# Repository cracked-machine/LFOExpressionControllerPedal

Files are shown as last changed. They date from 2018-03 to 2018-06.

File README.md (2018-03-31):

# LFOExpressionControllerPedal
This pedal replaces the traditional treadle/rocker expression pedal as an input into other guitar effects pedals.
Traditional expression pedals allow the player to control a variable resistance via an analog potentiometer in the expression pedal. This pedal creates an LFO signal that sweeps a digital potentiometer. 

The DSP is provided by an ATMEGA328P MCU, which transmits the binary encoded waveform data to a MCP41050 digital potentiometer via SPI. Eight waveforms are available: Sine, Square, RampUp, RampDown, Triangle, 8Step, 4Step and Pulse.
These waveforms can be selected via a single SPDT switch. LEDs indicate the selected waveform. A separate analog pot adjusts the frequency speed.

Documentation:

<ul>
  <li><a href="Hardware/SMT/documentation/LFOControllerPedal_SMT.xml">BOM</a></li>
  <li><a href="Hardware/SMT/documentation/LFOExpController_SMT.pdf">Schematic</a></li>
  <li><a href="Hardware/SMT/documentation/LFOExpController_SMT-TOPbrd.svg">Board Layout (TOP)</a></li>
  <li><a href="Hardware/SMT/documentation/LFOExpController_SMT-BOTTOMbrd.svg">Board Layout (BOTTOM)</a></li>
</ul>

<a href="https://github.com/cracked-machine/LFOExpressionControllerPedal">Github</a>|
<a href="https://cracked-machine.github.io/LFOExpressionControllerPedal/">Pages</a>

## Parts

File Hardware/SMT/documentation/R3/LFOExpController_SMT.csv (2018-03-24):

Reference | Value | Footprint | Datasheet
Y_AVRCLK1 | 16MHz | Crystals:Crystal_HC49-4H_Vertical
C_AVRCLK1 | 22pF | Capacitors_SMD:C_0805_HandSoldering
C_AVRCLK2 | 22pF | Capacitors_SMD:C_0805_HandSoldering
C2 | 100nF | Capacitors_SMD:C_0805_HandSoldering
SW_FUNC1 | SW_Push | Buttons_Switches_THT:SW_PUSH_6mm_h5mm
R_FUNC1 | 1K | Resistors_SMD:R_0805_HandSoldering
R_FREQ1 | B1K | Potentiometers:Potentiometer_Bourns_PTV09A-1_Horizontal
R1 | 330R | Resistors_SMD:R_0805_HandSoldering
R3 | 1K | Resistors_SMD:R_0805_HandSoldering
C1 | 100nF | Capacitors_SMD:C_0805_HandSoldering
D_WLED1 | LED | LEDs:LED_0805_HandSoldering
J_ISP1 | Conn_01x04 | Pin_Headers:Pin_Header_Straight_1x04_Pitch2.54mm
SW_EN1 | SW_DPDT_x2 | DPDT_FOOT_ONON_ALPHA_W13MM_D12MM_P5:DPDT_FOOT_ONON_ALPHA_W13MM_D12MM_P5.08MM
R_EN1 | 1K | Resistors_SMD:R_0805_HandSoldering
D_EN1 | LED | LEDs:LED_0805_HandSoldering
R_WLEDA1 | 1K | Resistors_SMD:R_0805_HandSoldering
D_WLED2 | LED | LEDs:LED_0805_HandSoldering
R_WLEDA2 | 1K | Resistors_SMD:R_0805_HandSoldering
D_WLED3 | LED | LEDs:LED_0805_HandSoldering
R_WLEDA3 | 1K | Resistors_SMD:R_0805_HandSoldering
D_WLED4 | LED | LEDs:LED_0805_HandSoldering
R_WLEDA4 | 1K | Resistors_SMD:R_0805_HandSoldering
D_WLED5 | LED | LEDs:LED_0805_HandSoldering
R_WLEDA5 | 1K | Resistors_SMD:R_0805_HandSoldering
D_WLED6 | LED | LEDs:LED_0805_HandSoldering
R_WLEDA6 | 1K | Resistors_SMD:R_0805_HandSoldering
U_9REG5 | LM317_3PinPackage | TO_SOT_Packages_SMD:SOT-223-3_TabPin2
U_WLEDMUX1 | _4051 | Housings_SOIC:SOIC-16_3.9x9.9mm_Pitch1.27mm
J_DC1 | _Barrel_Jack | Connectors:BARREL_JACK
U_AVR1 | _ATMEGA168A-AU | Housings_QFP:TQFP-32_7x7mm_Pitch0.8mm
D_InProtect1 | _D_Schottky | Diodes_SMD:D_SOD-123
J_OUT1 | Audio-Jack-3_3Switches | TRS635mmJack:TRS635mmJack
R_DB1 | 1K | Resistors_SMD:R_0805_HandSoldering
C_DB1 | 1uF | Capacitors_SMD:C_0805_HandSoldering
R_MUXIN1 | 470R | Resistors_SMD:R_0805_HandSoldering
C_BP1 | 100nF | Capacitors_SMD:C_0805_HandSoldering
C_BP5 | 100nF | Capacitors_SMD:C_0805_HandSoldering
J_MAIN2AUX1 | Conn_01x08 | Pin_Headers:Pin_Header_Straight_1x08_Pitch2.54mm
JP_GND1 | Jumper_NC_Dual | NetTie-II_SMD_FakeConnected:NetTie-II_SMD_GraphicallyConnected
U_DIGPOT1 | _MCP41050 | Housings_SOIC:SOIC-8_3.9x4.9mm_Pitch1.27mm
J_AUX2MAIN1 | _Conn_01x08 | Pin_Headers:Pin_Header_Straight_1x08_Pitch2.54mm

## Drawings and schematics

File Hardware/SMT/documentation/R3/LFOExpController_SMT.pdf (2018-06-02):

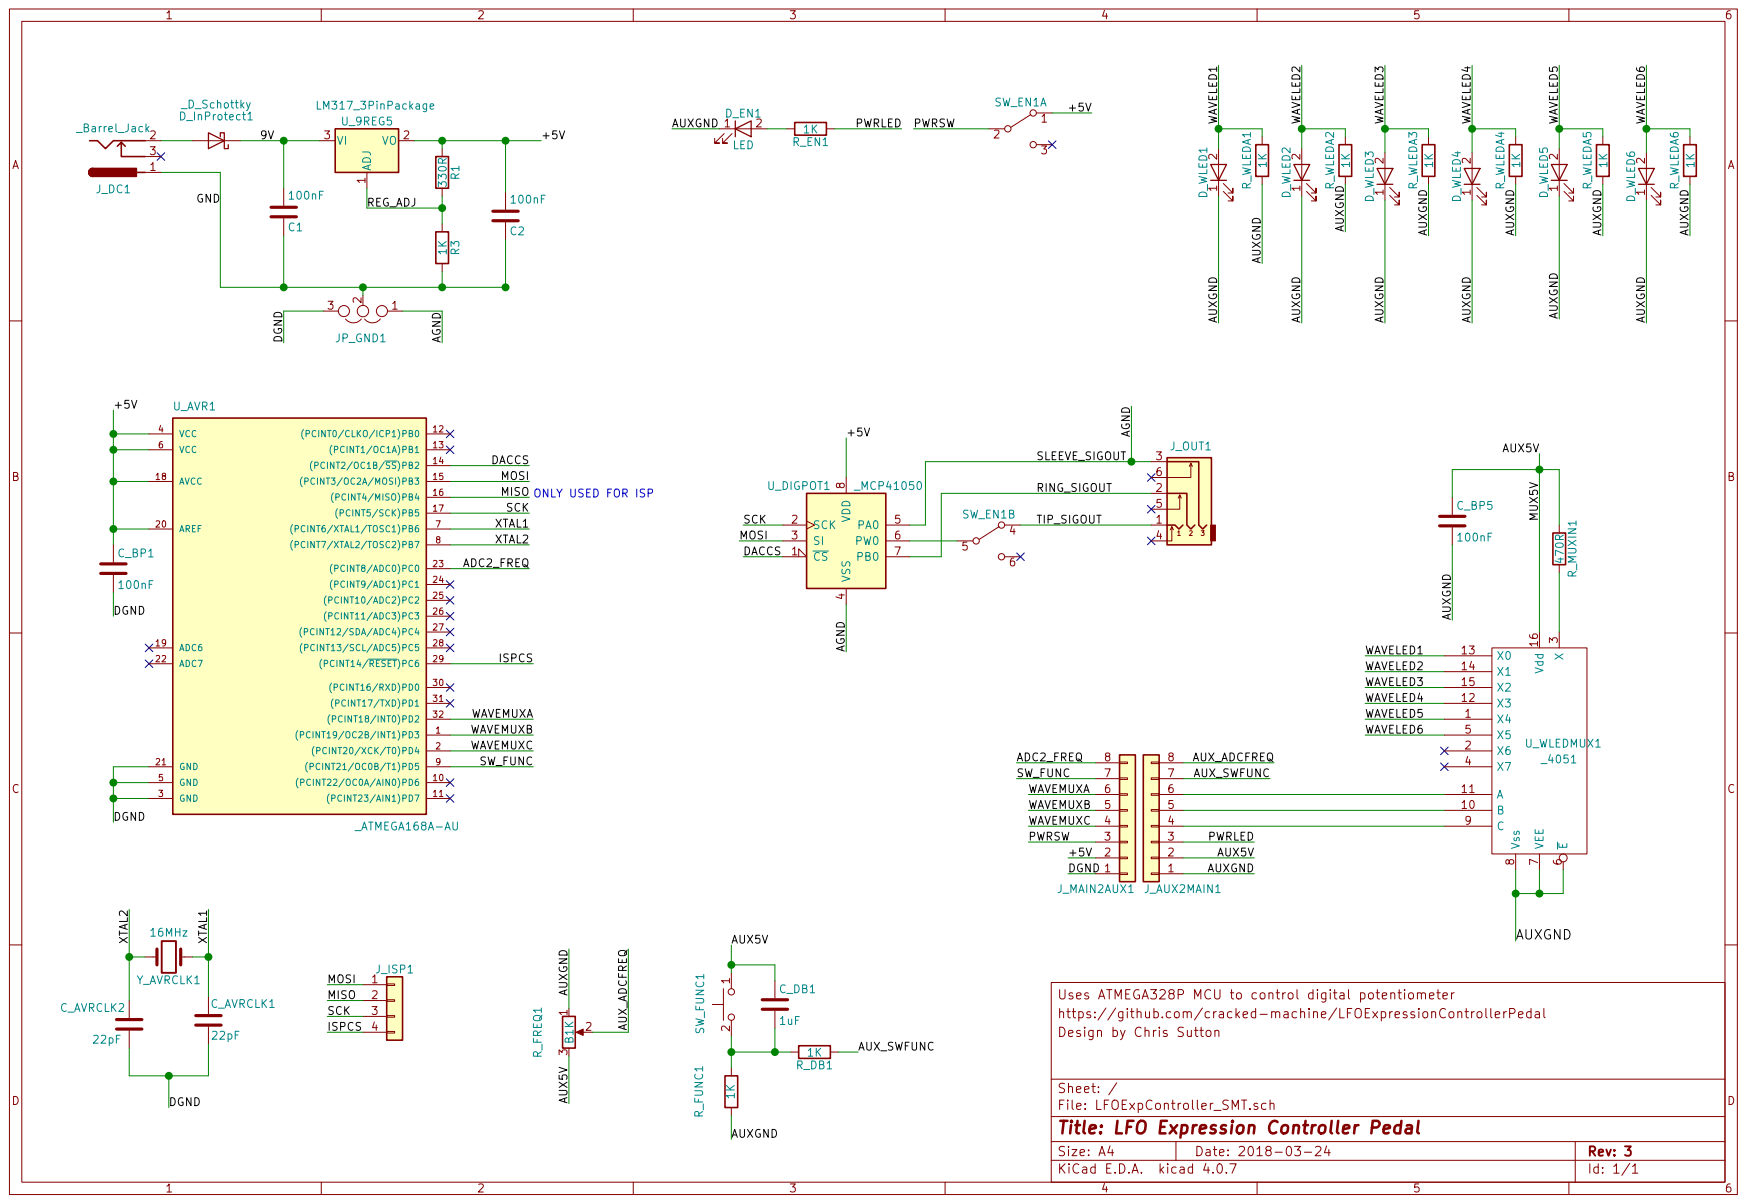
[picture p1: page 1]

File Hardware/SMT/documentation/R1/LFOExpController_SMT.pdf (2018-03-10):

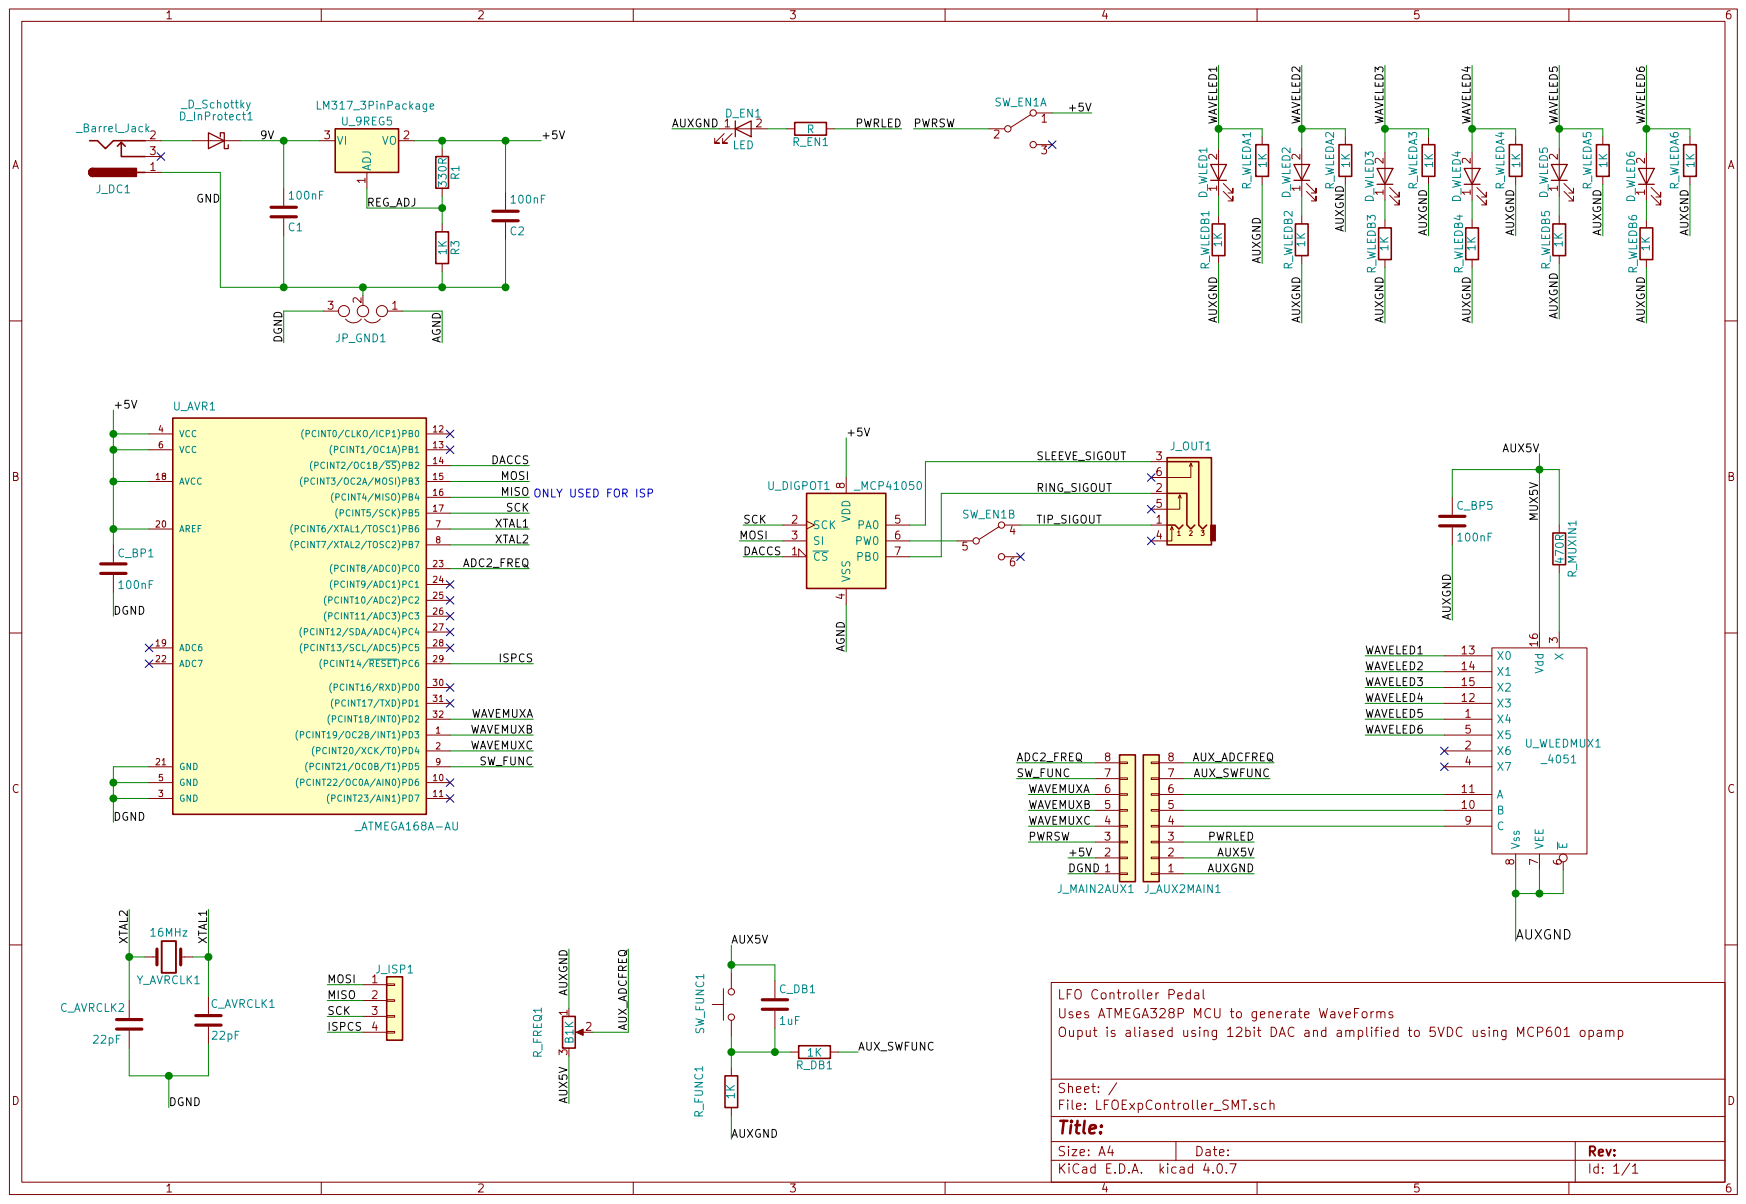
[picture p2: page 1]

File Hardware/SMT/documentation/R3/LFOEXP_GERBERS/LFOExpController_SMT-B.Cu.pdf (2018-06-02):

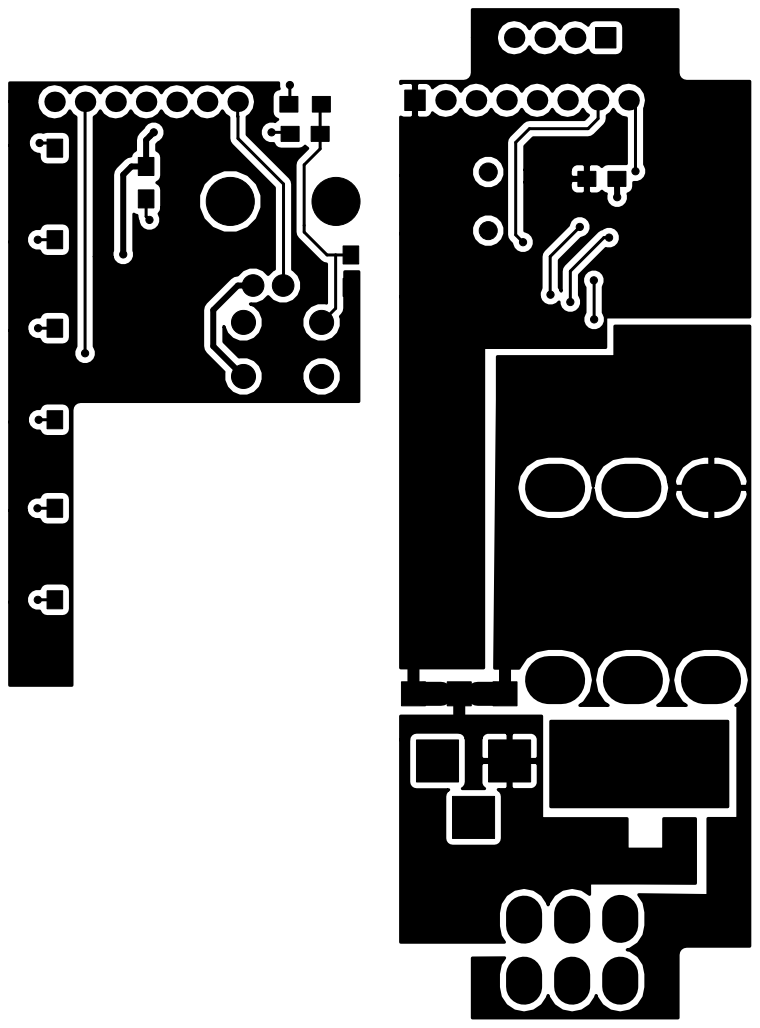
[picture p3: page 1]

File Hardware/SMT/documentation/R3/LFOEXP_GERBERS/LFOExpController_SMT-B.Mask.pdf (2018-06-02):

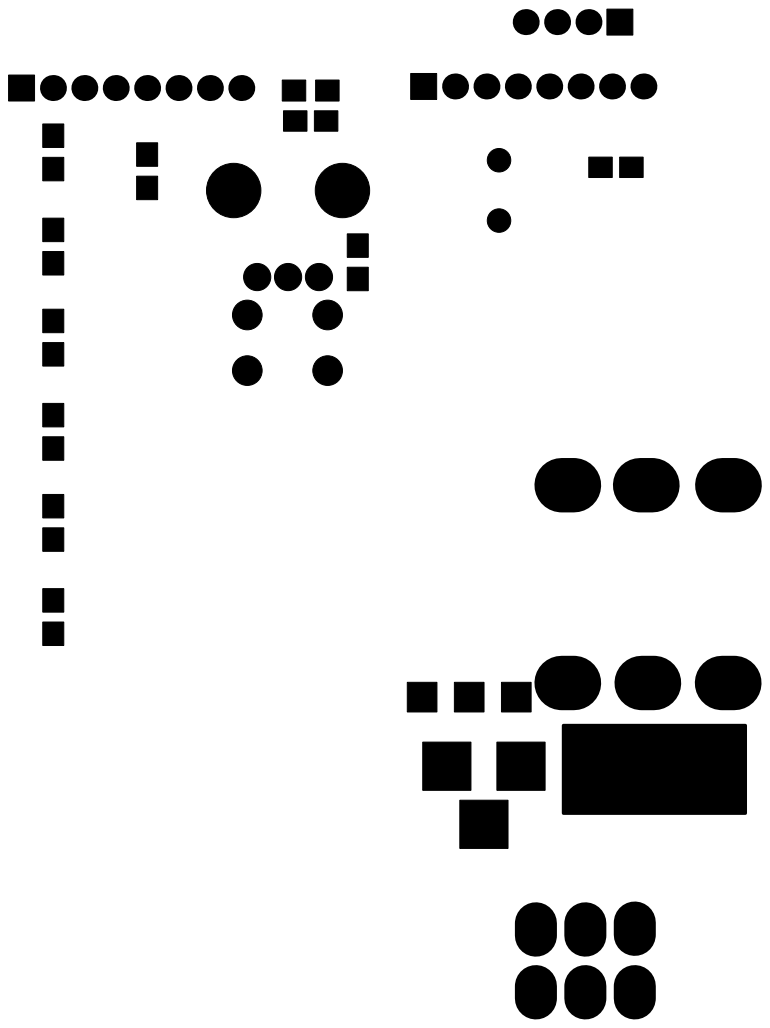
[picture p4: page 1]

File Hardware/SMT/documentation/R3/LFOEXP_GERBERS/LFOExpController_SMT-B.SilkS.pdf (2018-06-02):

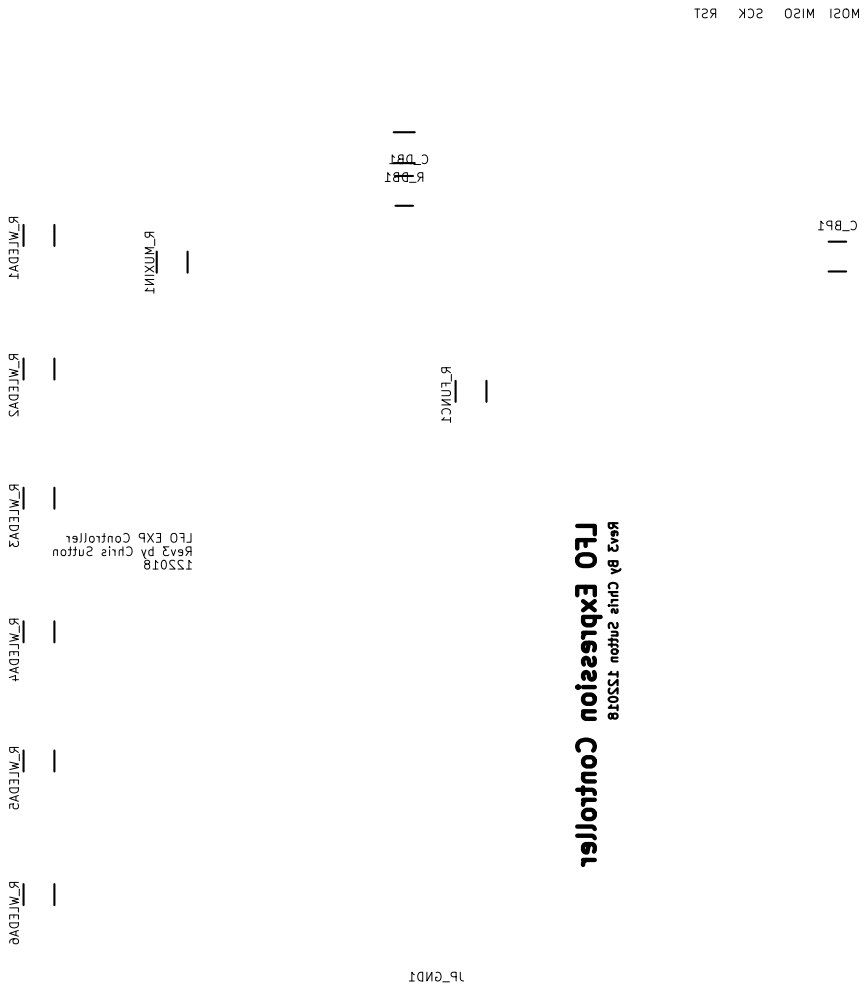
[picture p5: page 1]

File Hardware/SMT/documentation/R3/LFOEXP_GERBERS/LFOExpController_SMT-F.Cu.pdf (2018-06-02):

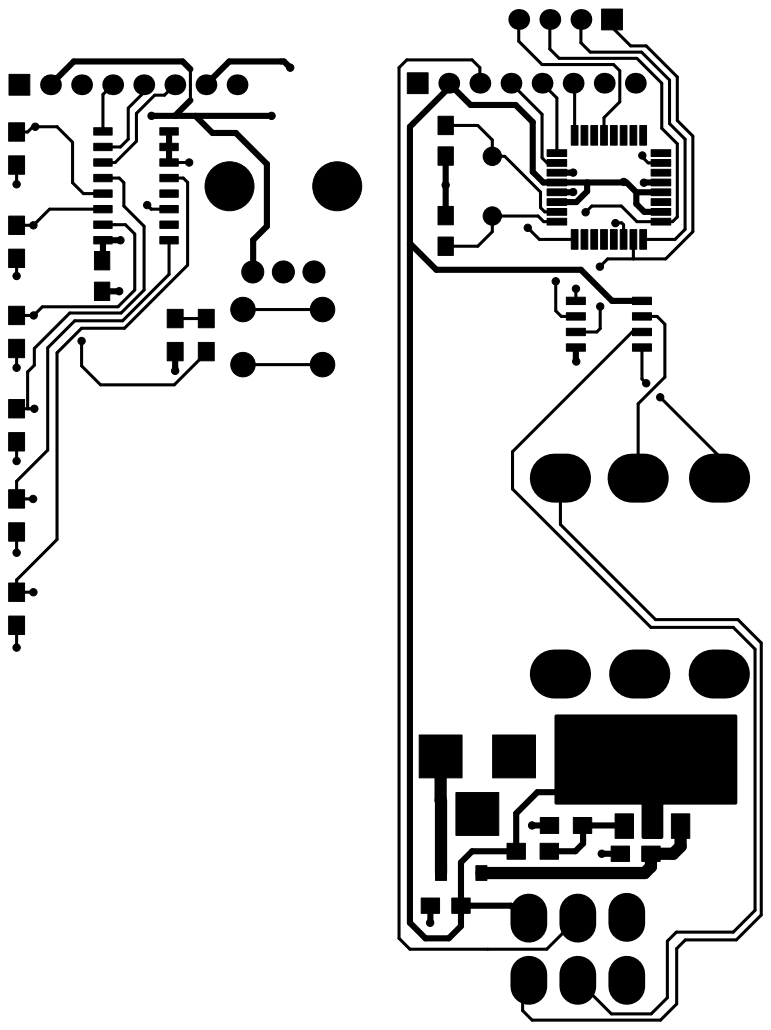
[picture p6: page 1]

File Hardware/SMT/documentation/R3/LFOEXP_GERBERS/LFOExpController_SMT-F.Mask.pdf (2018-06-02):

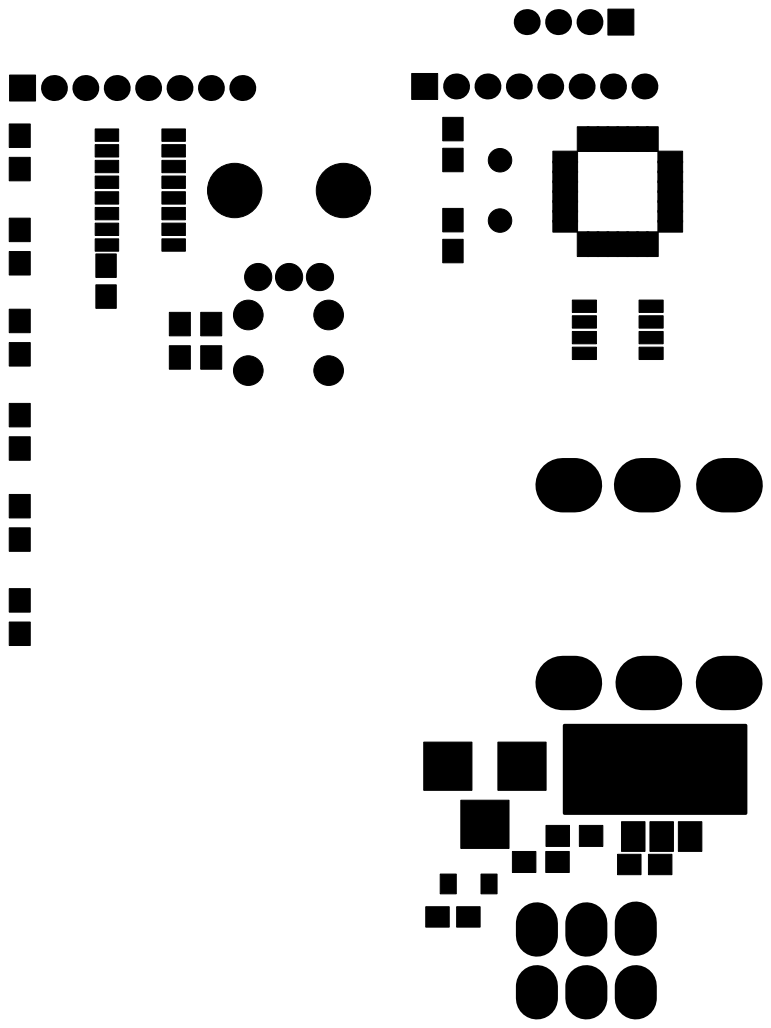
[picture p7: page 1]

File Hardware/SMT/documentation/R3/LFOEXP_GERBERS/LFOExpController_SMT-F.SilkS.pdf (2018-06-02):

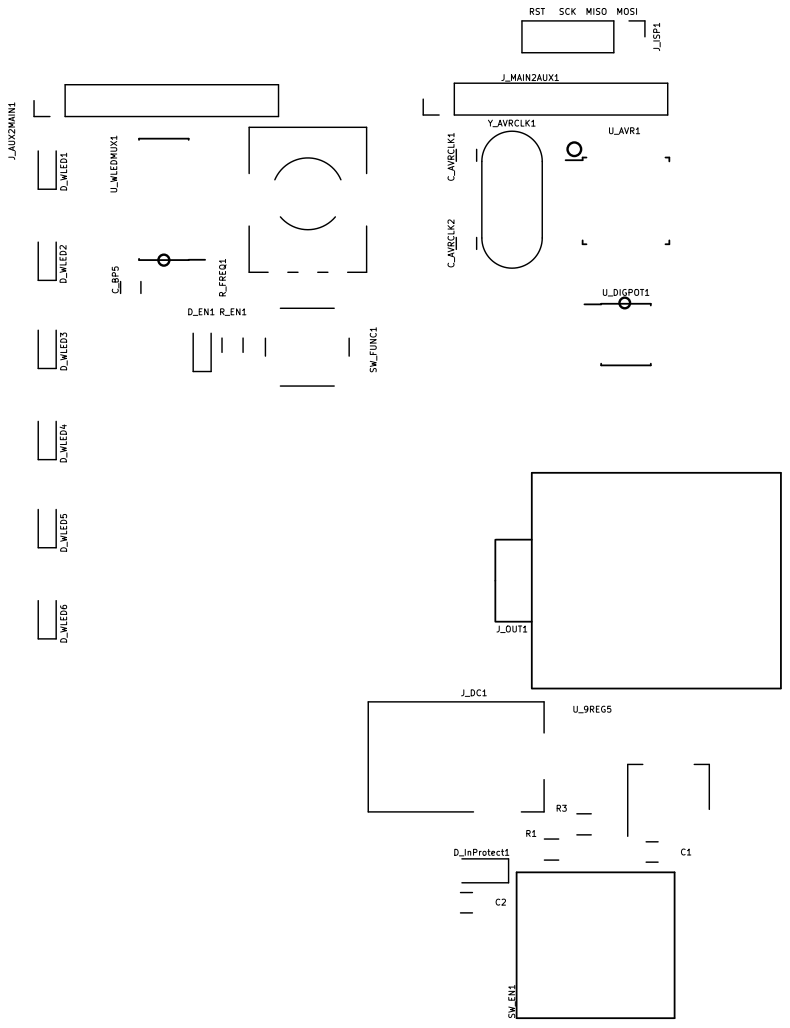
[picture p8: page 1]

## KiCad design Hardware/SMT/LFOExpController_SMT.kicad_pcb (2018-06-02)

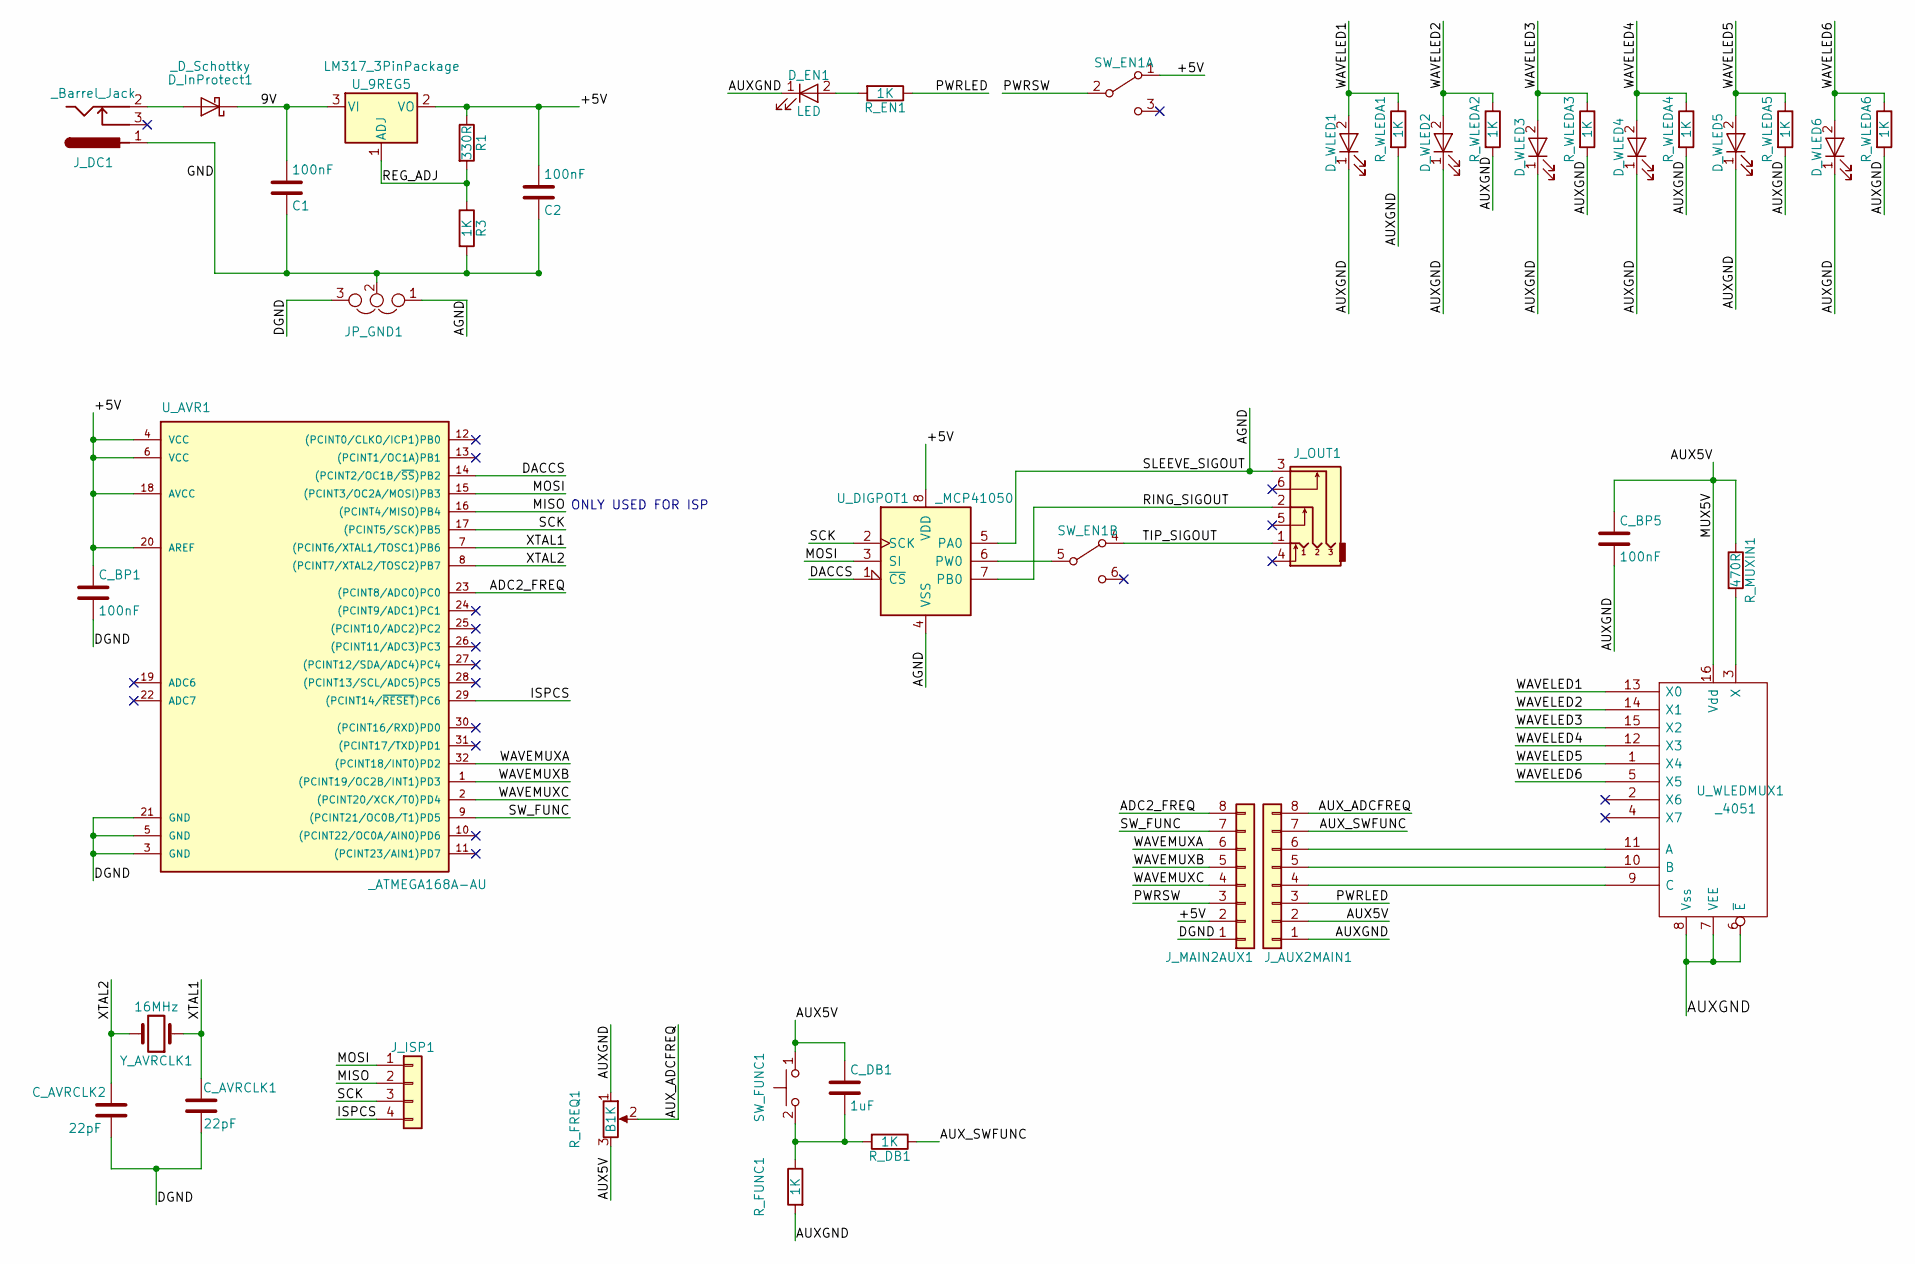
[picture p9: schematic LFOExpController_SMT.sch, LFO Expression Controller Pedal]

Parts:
C1, C2: 100nF; C_0805_HandSoldering
C_AVRCLK1, C_AVRCLK2: 22pF; C_0805_HandSoldering
C_BP1, C_BP5: 100nF; C_0805_HandSoldering
C_DB1: 1uF; C_0805_HandSoldering
D_EN1: LED; LED_0805_HandSoldering
D_InProtect1: _D_Schottky; D_SOD-123
D_WLED1, D_WLED2, D_WLED3, D_WLED4, D_WLED5, D_WLED6: LED; LED_0805_HandSoldering
JP_GND1: Jumper_NC_Dual; NetTie-II_SMD_GraphicallyConnected
J_AUX2MAIN1: _Conn_01x08; Pin_Header_Straight_1x08_Pitch2.54mm
J_DC1: _Barrel_Jack; BARREL_JACK
J_ISP1: Conn_01x04; Pin_Header_Straight_1x04_Pitch2.54mm
J_MAIN2AUX1: Conn_01x08; Pin_Header_Straight_1x08_Pitch2.54mm
J_OUT1: Audio-Jack-3_3Switches; TRS635mmJack
R1: 330R; R_0805_HandSoldering
R3: 1K; R_0805_HandSoldering
R_DB1: 1K; R_0805_HandSoldering
R_EN1: 1K; R_0805_HandSoldering
R_FREQ1: B1K; Potentiometer_Bourns_PTV09A-1_Horizontal
R_FUNC1: 1K; R_0805_HandSoldering
R_MUXIN1: 470R; R_0805_HandSoldering
R_WLEDA1, R_WLEDA2, R_WLEDA3, R_WLEDA4, R_WLEDA5, R_WLEDA6: 1K; R_0805_HandSoldering
SW_EN1: SW_DPDT_x2; DPDT_FOOT_ONON_ALPHA_W13MM_D12MM_P5.08MM
SW_FUNC1: SW_Push; SW_PUSH_6mm_h5mm
U_9REG5: LM317_3PinPackage; SOT-223-3_TabPin2
U_AVR1: _ATMEGA168A-AU; TQFP-32_7x7mm_Pitch0.8mm
U_DIGPOT1: _MCP41050; SOIC-8_3.9x4.9mm_Pitch1.27mm
U_WLEDMUX1: _4051; SOIC-16_3.9x9.9mm_Pitch1.27mm
Y_AVRCLK1: 16MHz; Crystal_HC49-4H_Vertical

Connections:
/9V: C1.2, D_InProtect1.1 (K), U_9REG5.3 (VI)
/+5V: C2.2, C_BP1.1, J_MAIN2AUX1.2, R1.1, SW_EN1.1 (A), U_9REG5.2 (VO), U_AVR1.4 (VCC), U_AVR1.6 (VCC), U_AVR1.18 (AVCC), U_AVR1.20 (AREF), U_DIGPOT1.8 (VDD)
/ADC2_FREQ: J_MAIN2AUX1.8, U_AVR1.23 ((PCINT8/ADC0)PC0)
/AGND: JP_GND1.1, J_OUT1.3, U_DIGPOT1.4 (VSS), U_DIGPOT1.5 (PA0)
/AUX5V: C_BP5.1, C_DB1.1, J_AUX2MAIN1.2, R_FREQ1.3, R_MUXIN1.1, SW_FUNC1.1, U_WLEDMUX1.16 (Vdd)
/AUXGND: C_BP5.2, D_EN1.1 (K), D_WLED1.1 (K), D_WLED2.1 (K), D_WLED3.1 (K), D_WLED4.1 (K), D_WLED5.1 (K), D_WLED6.1 (K), J_AUX2MAIN1.1, R_FREQ1.1, R_FUNC1.2, R_WLEDA1.2, R_WLEDA2.2, R_WLEDA3.2, R_WLEDA4.2, R_WLEDA5.2, R_WLEDA6.2, U_WLEDMUX1.6 (~E), U_WLEDMUX1.7 (VEE), U_WLEDMUX1.8 (Vss)
/AUX_ADCFREQ: J_AUX2MAIN1.8, R_FREQ1.2
/AUX_SWFUNC: J_AUX2MAIN1.7, R_DB1.1
/DACCS: U_AVR1.14 ((PCINT2/OC1B/~SS~)PB2), U_DIGPOT1.1 (~CS)
/DGND: C_AVRCLK1.1, C_AVRCLK2.1, C_BP1.2, JP_GND1.3, J_MAIN2AUX1.1, U_AVR1.3 (GND), U_AVR1.5 (GND), U_AVR1.21 (GND)
/GND: C1.1, C2.1, JP_GND1.2, J_DC1.1, R3.2
/ISPCS: J_ISP1.4, U_AVR1.29 ((PCINT14/~RESET~)PC6)
/MISO: J_ISP1.2, U_AVR1.16 ((PCINT4/MISO)PB4)
/MOSI: J_ISP1.1, U_AVR1.15 ((PCINT3/OC2A/MOSI)PB3), U_DIGPOT1.3 (SI)
/PWRLED: J_AUX2MAIN1.3, R_EN1.1
/PWRSW: J_MAIN2AUX1.3, SW_EN1.2 (B)
/REG_ADJ: R1.2, R3.1, U_9REG5.1 (ADJ)
/RING_SIGOUT: J_OUT1.2, U_DIGPOT1.7 (PB0)
/SCK: J_ISP1.3, U_AVR1.17 ((PCINT5/SCK)PB5), U_DIGPOT1.2 (SCK)
/SW_FUNC: J_MAIN2AUX1.7, U_AVR1.9 ((PCINT21/OC0B/T1)PD5)
/TIP_SIGOUT: J_OUT1.1, SW_EN1.4 (A)
/WAVELED1: D_WLED1.2 (A), R_WLEDA1.1, U_WLEDMUX1.13 (X0)
/WAVELED2: D_WLED2.2 (A), R_WLEDA2.1, U_WLEDMUX1.14 (X1)
/WAVELED3: D_WLED3.2 (A), R_WLEDA3.1, U_WLEDMUX1.15 (X2)
/WAVELED4: D_WLED4.2 (A), R_WLEDA4.1, U_WLEDMUX1.12 (X3)
/WAVELED5: D_WLED5.2 (A), R_WLEDA5.1, U_WLEDMUX1.1 (X4)
/WAVELED6: D_WLED6.2 (A), R_WLEDA6.1, U_WLEDMUX1.5 (X5)
/WAVEMUXA: J_MAIN2AUX1.6, U_AVR1.32 ((PCINT18/INT0)PD2)
/WAVEMUXB: J_MAIN2AUX1.5, U_AVR1.1 ((PCINT19/OC2B/INT1)PD3)
/WAVEMUXC: J_MAIN2AUX1.4, U_AVR1.2 ((PCINT20/XCK/T0)PD4)
/XTAL1: C_AVRCLK1.2, U_AVR1.7 ((PCINT6/XTAL1/TOSC1)PB6), Y_AVRCLK1.1
/XTAL2: C_AVRCLK2.2, U_AVR1.8 ((PCINT7/XTAL2/TOSC2)PB7), Y_AVRCLK1.2
unnamed: C_DB1.2, R_DB1.2, R_FUNC1.1, SW_FUNC1.2
unnamed: D_EN1.2 (A), R_EN1.2
unnamed: D_InProtect1.2 (A), J_DC1.2
unnamed: J_AUX2MAIN1.4, U_WLEDMUX1.9 (C)
unnamed: J_AUX2MAIN1.5, U_WLEDMUX1.10 (B)
unnamed: J_AUX2MAIN1.6, U_WLEDMUX1.11 (A)
unnamed: R_MUXIN1.2, U_WLEDMUX1.3 (X)
unnamed: SW_EN1.5 (B), U_DIGPOT1.6 (PW0)

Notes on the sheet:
ONLY USED FOR ISP

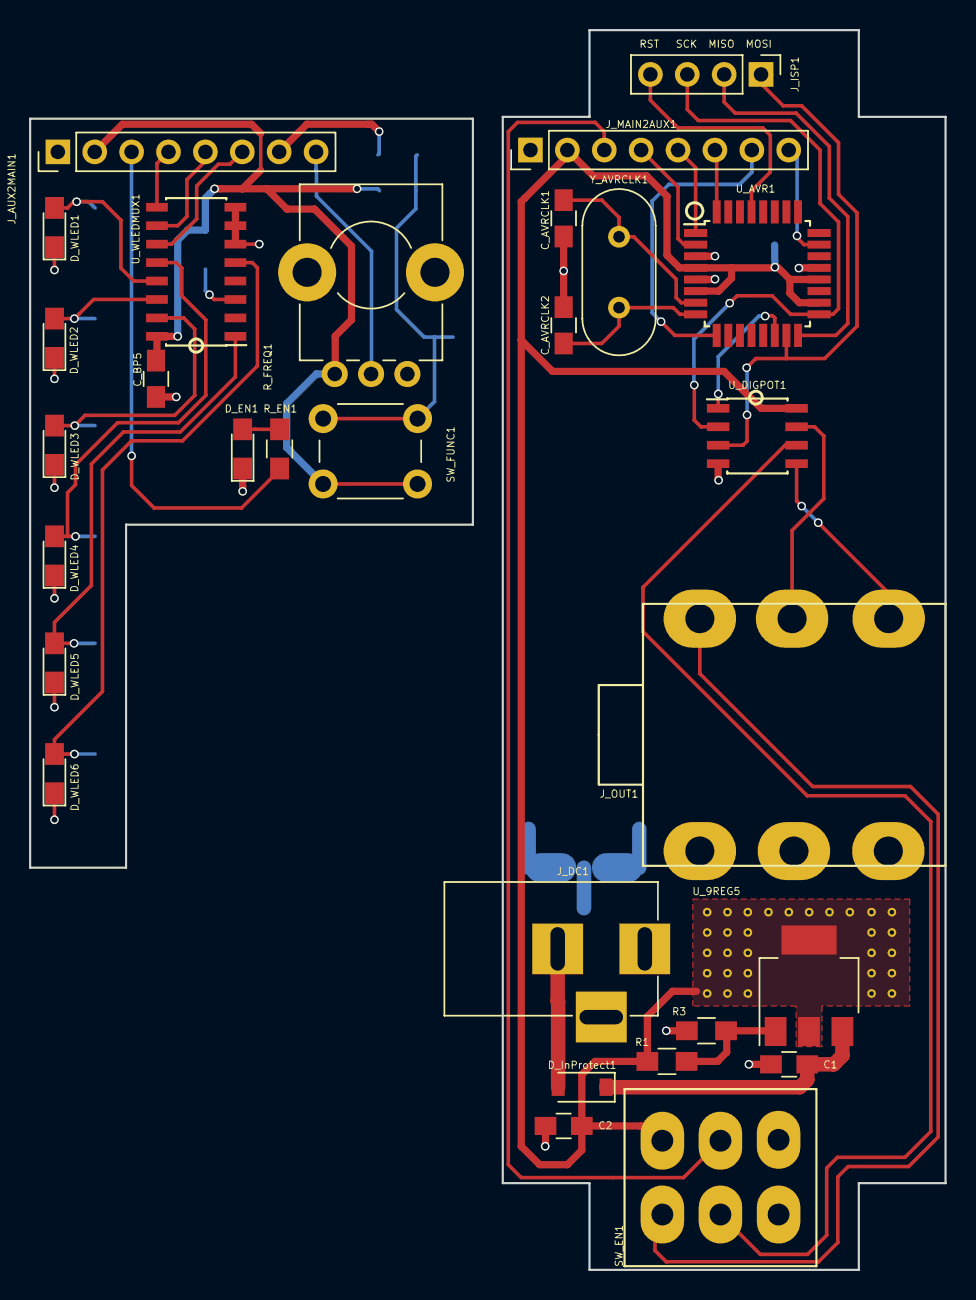
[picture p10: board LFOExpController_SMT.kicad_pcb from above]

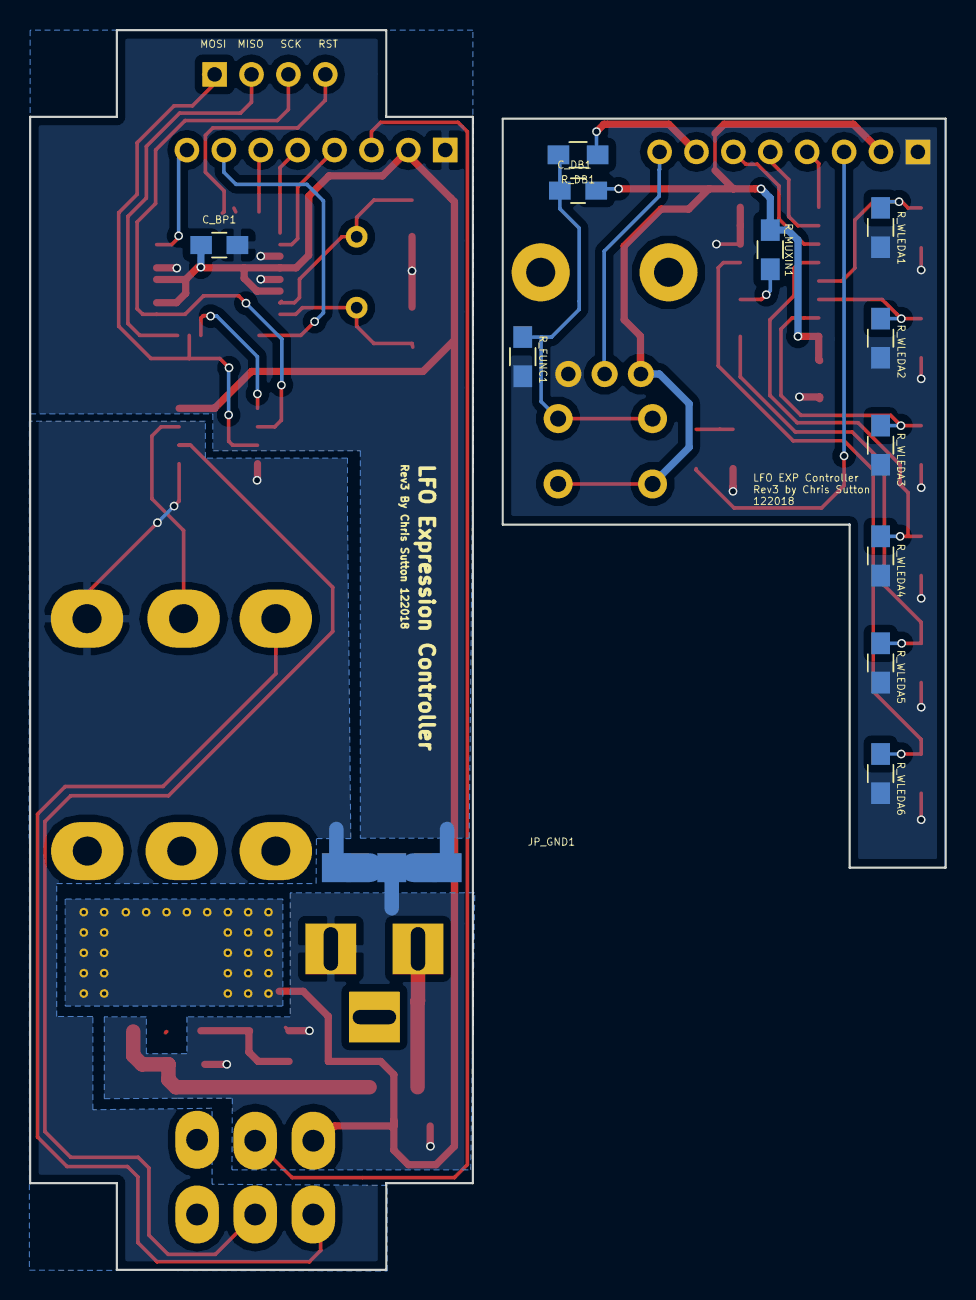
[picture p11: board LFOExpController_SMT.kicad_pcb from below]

Board: 2 copper layers, 63.0 x 85.3 mm, 41 parts (12 on the bottom side), 40 nets.

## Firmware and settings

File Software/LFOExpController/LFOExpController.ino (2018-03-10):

// DWG auxiliary source
#include "LFOExpController_CLK.h"
#include "LFOExpController_SPI.h"



unsigned long DWG_LastDebounceTime = 0;  // the last time the output pin was toggled
unsigned long DWG_DebounceDelay = 400;    // the debounce time; increase if the output flickers
volatile uint8_t DWG_Portdhistory = 0xFF; 

void setup() {
  Serial.begin(9600);
 
  
  PCI_Setup();
  CLK_Setup();
  DSP_Setup();
  SPI_Setup();
  ADC_Setup();
  
}

void loop() {
  int _freqLow = 2;         // increases lower limit of frequency range
  int _logTaper = 384;      // audio/log taper 
  
  if (ADC_FreqInput > 10) {
    // add log taper so that linear potentiometer can be used.
    OCR1A = map(ADC_FreqInput * _freqLow, 0, 1023, 0, _logTaper);
    
  }
  // set LED based on value of DSP_Waveform
  PCI_SetMUX();

}

/////////////////////////////////////////////
/////////////////////////////////////////////
/////  ITERRUPT SERVICE ROUTINES
/////////////////////////////////////////////
/////////////////////////////////////////////



ISR(TIMER1_OVF_vect) {
   // reset SPI pins...?
    DDRB |= _BV(_SS);               // set SS pin to output before enabling SPI (req. for master)
    SPCR |=  _BV(SPE) | _BV(MSTR);  // enable spi as master
    //DDRB |= _BV(_SCK) | _BV(_MOSI); // set pins to output
 
   SPI_SendData();
}

// Interrupt service routine for the ADC completion
ISR(ADC_vect){
  
  
  ADCInput = ADCL;
  ADCInput += ADCH << 8;

  
   switch(ADMUX) {
    case 0x00:
      ADC_FreqInput = ADCInput;
      
     // ADMUX = 0x01;
    break;
    
    /*case 0x01:
      ADC_FreqInput = ADCInput;
      ADMUX = 0x00;
    break;
    */
    
    
  }
  ADCSRA |= _BV(ADSC);
 
}

ISR(PCINT2_vect) {  
   //Serial.println("Test");
    if(PIND & _BV(PCI_WaveIncrPin)) {
      
      (DSP_Waveform == PULSE) ? DSP_Waveform = SINE : DSP_Waveform++;      
      PCI_SetMUX();
      
     
    }
  
}

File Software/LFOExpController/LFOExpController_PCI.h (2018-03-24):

#ifndef DWG_PCI_H_
#define DWG_PCI_H_

// see CD74HCT4051 MUX datasheet function table
// we are using PIND2, PIND3 and PIND4 on the ATMEGA328P to send addresses to MUX
#define MUXCLEAR 0x00    // 000 // 
#define MUXS0 0x02    // 001
#define MUXS1 0x03    // 010  
#define MUXS2 0x04    // 100



// 0x02 2+3
// 0x03 1+3
// 0x04 1+2
// 0x0

/////  ATMEGA328P reference PORTD pin-2-interrupt
// PIND0 = PCINT16
// PIND1 = PCINT17
// PIND2 = PCINT18
// PIND3 = PCINT19
// PIND4 = PCINT20
// PIND5 = PCINT21
// PIND6 = PCINT22
// PIND7 = PCINT23

// PCI_WaveIncrPin. must change BOTH. See above for reference.
int PCI_WaveIncrPin = PIND5; 
int PCI_WaveIncInt = PCINT21;

int PCI_MUXPIN0 = PIND2;
int PCI_MUXPIN1 = PIND3;
int PCI_MUXPIN2 = PIND4;

void PCI_Setup() {
  
  //set PCI_WaveIncrPin = INPUT (0), PCI_MUXS0 = OUTPUT (1)
  DDRD |= ~_BV(PCI_WaveIncrPin) | _BV(PCI_MUXPIN0) | _BV(PCI_MUXPIN1) | _BV(PCI_MUXPIN2);
  
  
  //set PCI_WaveIncrPin = Hi-Z (1)
  PORTD |= _BV(PCI_WaveIncrPin) | _BV(PCI_MUXPIN0) | _BV(PCI_MUXPIN1) | _BV(PCI_MUXPIN2) ;

  //pinMode(PCI_WaveIncrPin, INPUT);
  //pinMode(PCI_MUXPIN0, OUTPUT);
  //pinMode(PCI_MUXPIN1, OUTPUT);
  //pinMode(PCI_MUXPIN2, OUTPUT);
  
  
  PCICR |= _BV(PCIE2);      // enable interrupts for PD 0-7 ports (PCINT16-23)
  PCMSK2 |= _BV(PCI_WaveIncInt) ;   // enable interrupts for PCI_WaveIncrPin
   
}

void PCI_SetMUX() {
  switch(DSP_Waveform) {
        
        case SINE:
            // A0 = LLL
            digitalWrite(PCI_MUXPIN2, LOW);
            digitalWrite(PCI_MUXPIN1, LOW);
            digitalWrite(PCI_MUXPIN0, LOW);
          
          break;
        case TRIANGLE:
            // A1 = LLH
            digitalWrite(PCI_MUXPIN2, LOW);
            digitalWrite(PCI_MUXPIN1, LOW);
            digitalWrite(PCI_MUXPIN0, HIGH);
          break;
        case RAMPUP:
            // A2 = LHL
            digitalWrite(PCI_MUXPIN2, LOW);
            digitalWrite(PCI_MUXPIN1, HIGH);
            digitalWrite(PCI_MUXPIN0, LOW);
          break;
        case STEP4:
            //A3 = LHH
            digitalWrite(PCI_MUXPIN2, LOW);
            digitalWrite(PCI_MUXPIN1, HIGH);
            digitalWrite(PCI_MUXPIN0, HIGH);
          break;
          
        case SQUARE:
            //A4 = HLL
            digitalWrite(PCI_MUXPIN2, HIGH);
            digitalWrite(PCI_MUXPIN1, LOW);
            digitalWrite(PCI_MUXPIN0, LOW);
          break;
         
        case PULSE:
            //A5 = HLH
            digitalWrite(PCI_MUXPIN2, HIGH);
            digitalWrite(PCI_MUXPIN1, LOW);
            digitalWrite(PCI_MUXPIN0, HIGH);
          break;
         
        /*case STEP4:
            //A6 = HHL
            digitalWrite(PCI_MUXPIN2, HIGH);
            digitalWrite(PCI_MUXPIN1, HIGH);
            digitalWrite(PCI_MUXPIN0, LOW);
          break;
        case PULSE:
            //A7 = HHH
            digitalWrite(PCI_MUXPIN2, HIGH);
            digitalWrite(PCI_MUXPIN1, HIGH);
            digitalWrite(PCI_MUXPIN0, HIGH);
          break;
          */
      }

  
}

#endif

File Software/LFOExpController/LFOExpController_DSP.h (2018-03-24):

#ifndef DWG_DSP_H_
#define DWG_DSP_H_

//#define LOOKUP_TABLE_ENABLED

// all possible waveforms
enum DSP_EWAVEFORMS { SINE, TRIANGLE, RAMPUP, STEP4, SQUARE, PULSE } ;

// available waveforms. if you change this order make sure the last item matches one used  in PCINT2_vect condition!
DSP_EWAVEFORMS const DSP_Waveforms[] = { SINE, TRIANGLE, RAMPUP, STEP4, SQUARE, PULSE };

// current selected waveform
int DSP_Waveform;

// sine wave lookup table and sample rate. limit dictated by MCP41050
const int DSP_SampleResolution = 256;  

// counter variable used by all waveforms
int DSP_WaveIndex;

void DSP_Setup() {

  DSP_Waveform = SINE;
}

int DSP_GetAlgorithmicWaveData(DSP_EWAVEFORMS _Waveform) {
      int _multiplier;
      int _halfPeriod=DSP_SampleResolution/2;   // half period
      int _temp;                                 // temp allows serial print debug
      float _tri_temp=0;                        // triangle needs a float
   
      switch(_Waveform) {
          // cases must exist in DSP_EWAVEFORMS and DSP_Waveforms[] OR they MUST be commented out to build successfully!
          case SINE:     
              _temp = (cos(((2.0*PI)/DSP_SampleResolution)*DSP_WaveIndex))*(_halfPeriod-1);
              return _temp += (_halfPeriod-1);
            break;
          
          case SQUARE:
            return (DSP_WaveIndex++ % 256) < 128 ? (0xFF) : 0x00;
            break;

          case RAMPUP:
            _multiplier = 4;
            _temp = DSP_SampleResolution - (_multiplier * (DSP_WaveIndex/4));
            return _temp;
            break;
          
          /*case RAMPDOWN:
            _multiplier = 4;
            _temp = _multiplier * (DSP_WaveIndex/4);
            return _temp;
            break;
          */
          case TRIANGLE:  
            _multiplier = 2;
            _tri_temp = (_halfPeriod - abs(DSP_WaveIndex % (2 * _halfPeriod) - _halfPeriod) );
            _tri_temp = (DSP_SampleResolution-1) - ((_multiplier) * _tri_temp);
            return _tri_temp;
            break;
          /*
          case STEP8:
            _multiplier = 32;
            _temp = DSP_SampleResolution - (_multiplier * (DSP_WaveIndex/_multiplier));
            return _temp;
            break;
          */
          case STEP4:
            _multiplier = 64;
            _temp = DSP_SampleResolution - (_multiplier * (DSP_WaveIndex/_multiplier));
            return _temp;
            break;
            
          case PULSE:
            return (DSP_WaveIndex++ % 256) > 224 ? (0xFF) : 0x00;
            break;
      }
      
 
}





#endif 

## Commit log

2018-03-10 Completed Board Layout
    [LFOExpController_SMT.kicad_pcb, LFOExpController_SMT.sch]
2018-03-11 Generated GERBERS
    [LFOExpController_SMT-B.Cu.gbr, LFOExpController_SMT-B.Mask.gbr, LFOExpController_SMT-B.SilkS.gbr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]
2018-03-24 Revision3 update
    - Added ground to Jack sleeve pin
    - Corrected SW_FUNC circuit
    - Removed R_WLEDB LEDS
    - Modified firmware from eight wavepatterns to six, to allign with Hardware (Sine, Triangle, RampUp, Step4, Square, Pulse)
    - Created R3 documentation
    - Created new GERBERS
    [LFOExpController_SMT.csv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]
2018-03-24 save update
    [LFOExpController_SMT.kicad_pcb]
2018-06-02 board layout update
    - rotated freq pot 180 and moved up 5mm
    - narrowed led strip on daughter board
    [LFOExpController_SMT-B.Cu.gbr, LFOExpController_SMT-B.Mask.gbr, LFOExpController_SMT-B.SilkS.gbr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]
